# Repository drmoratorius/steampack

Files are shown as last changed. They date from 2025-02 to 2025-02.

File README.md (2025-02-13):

# Dr. Moratorius' SteamPack

**Last Update: 2025-02-13**

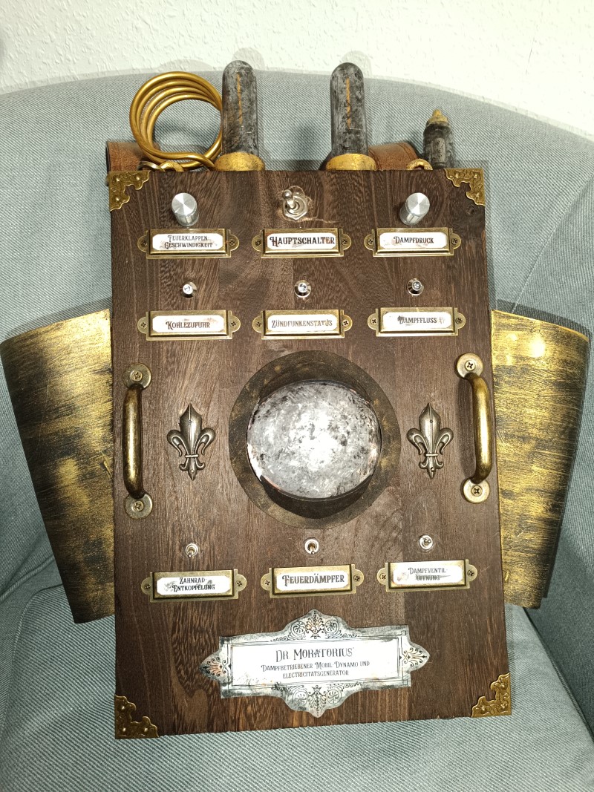
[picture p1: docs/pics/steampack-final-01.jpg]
SteamPack


This is a repository explaining how I built my steam pack and also provide 
all of the required files and information.
Please note that this is more a repository that can help you build your own
or adapt it and not a full tutorial.

## Features
* Powered by USB (power bank)
* Powered by Raspberry Pi Pico 2 W using MicroPython
* Wooden Backpack
* Sounds
* Timed steam (ultrasonic fogger) output with corresponding supporting steam sound
* Sounds when turning on and off certain parts (choose from 255 MP3 files on SD card!)
* and more!

## Electronics Setup
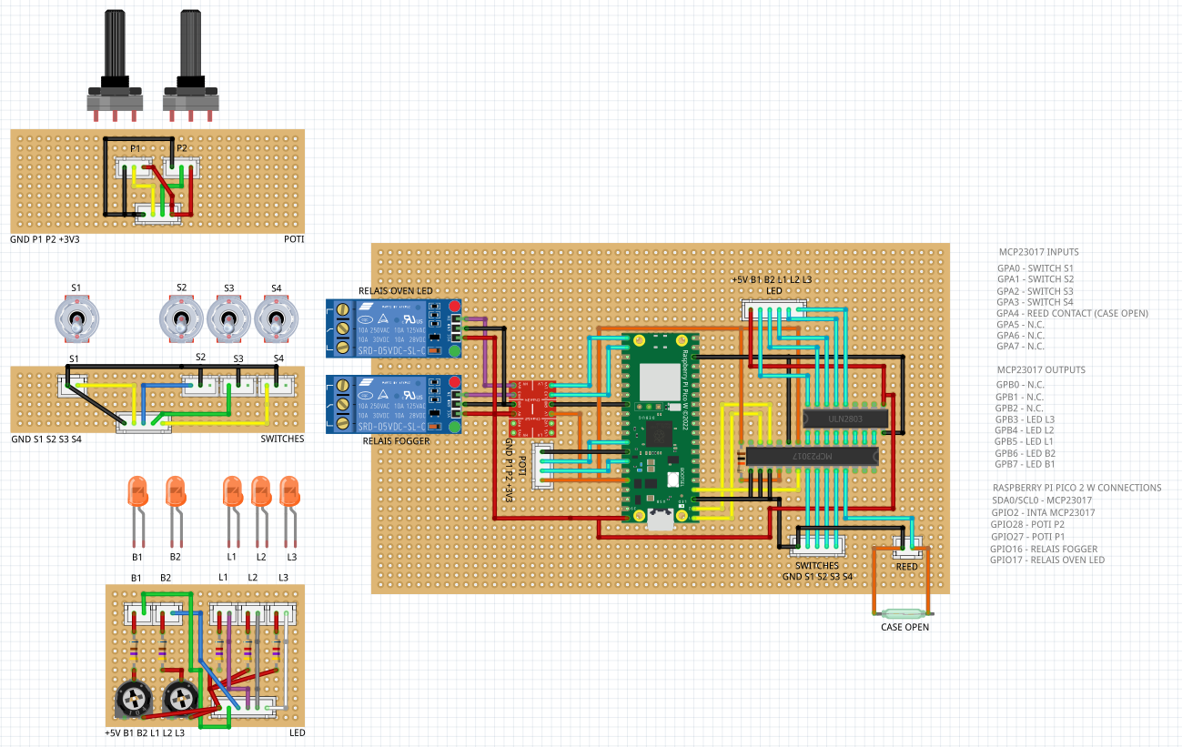
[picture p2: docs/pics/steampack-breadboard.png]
Breadboard

_Please note that this [Fritzing](https://fritzing.org/) layout does not yet contain the sound board!_
* [Raspberry Pi 2 Pico 2 W](https://www.raspberrypi.com/products/raspberry-pi-pico-2/)
* [MCP23017](https://www.microchip.com/en-us/product/mcp23017) (I²C) for handling switch inputs and LED, fogger and "fire" LED utilizing [ULN2803A](https://www.st.com/resource/en/datasheet/uln2804a.pdf) for switching the higher currents
* [MCP23017](https://www.microchip.com/en-us/product/mcp23017) (I²C) and sound board [DY-SV5W](https://grobotronics.com/images/companies/1/datasheets/DY-SV5W%20Voice%20Playback%20ModuleDatasheet.pdf) to play up to 255 different MP3 files from SD card
* separate potentiometer and switch and LED boards for easier placement inside box
* LED board includes potentiometers for setting the intensity
* fogger and LED "fire" switched via relay to enable usage of multiple powerbanks to keep main circuit powered even after draining the fogger or "fire" LED battery
* utilizes level shifters for handling 5V connected to 3V3 ports (relays, sound board)

## Components
* [parts list](docs/PARTS.MD)
* [labels (DOCX)](docs/Schilder.docx)
* [vial holder outer part pattern](docs/Schnittmuster.pdf) - print 100% (do not resize to printer edges) - does not fully cover outer part, but sufficient
* 3D printer files
  * [Vial holder (left) - STL](3d/Moratorius_Steampack_Vial_Holder_R.stl) 
  * [Vial holder (right) - STL](3d/Moratorius_Steampack_Vial_Holder_R.stl)
  * [Vial holder (left) - GCODE for Anycubic i3 MEGA](3d/AIM/AIM_Moratorius_Steampack_Vial_Holder_L.gcode)
  * [Vial holder (right) - GCODE for Anycubic i3 MEGA](3d/AIM/AIM_Moratorius_Steampack_Vial_Holder_R.gcode)
* [Fritzing breadboard layout](fritzing/DrMoratorius-SteamPack-Breadboard.fzz) - still missing schematic and audio part 

## Software
* The code uses the latest MicroPython download from https://www.raspberrypi.com/documentation/microcontrollers/micropython.html
* The source code is available in the `src` directory and still WIP!
* It loads most of the configuration from the `config.json` file, but some parts are (still) hardcoded
* Potential ideas for the future: allow control via smartphone through a WiFi AP

## Sounds
The used sound module [DY-SV5W](https://grobotronics.com/images/companies/1/datasheets/DY-SV5W%20Voice%20Playback%20ModuleDatasheet.pdf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) is using an
SD card (32 GB max, FAT32) with several sounds mixed from available sounds online. Here is a selection:
* https://freesound.org/people/qubodup/sounds/194882/
* https://freesound.org/people/qubodup/sounds/395041/
* https://freesound.org/people/mike_stranks/sounds/407394/
* https://freesound.org/people/craigsmith/sounds/438641/
* https://freesound.org/people/theshaggyfreak/sounds/440453/
* https://freesound.org/people/stib/sounds/487748/
* https://freesound.org/people/Engineer_815/sounds/493558/ (main steam sound used)
* https://freesound.org/people/rottako/sounds/693587/
* https://freesound.org/people/qubodup/sounds/752067/
* https://www.youtube.com/watch?v=LwiOCsfa_ZA (gear sounds)
* https://freesound.org/people/Vibratair/sounds/403892/ (electricity)
* https://freesound.org/people/Halleck/sounds/19487/ (electricity)
* https://freesound.org/people/Vibratair/sounds/403892/ (electricity)
* https://freesound.org/people/opyate/sounds/518945/ (on/off sound - off = reverted)

## How To Build
Please see the [HOWTO](HOWTO.MD)

## Partical Notes
If you use a power bank please keep in mind that most turn off completely if the attached device
does not use a lot of power requiring you to open the case and turn on the powerbank again.
For the future using 18650 cells (with additional protection circuit) with corresponding
charging board might be an option.

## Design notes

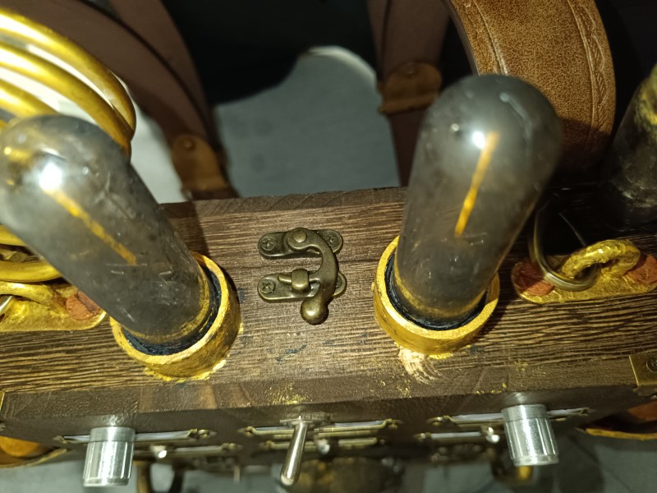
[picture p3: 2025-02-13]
docs/pics/steampack-final-05.jpg

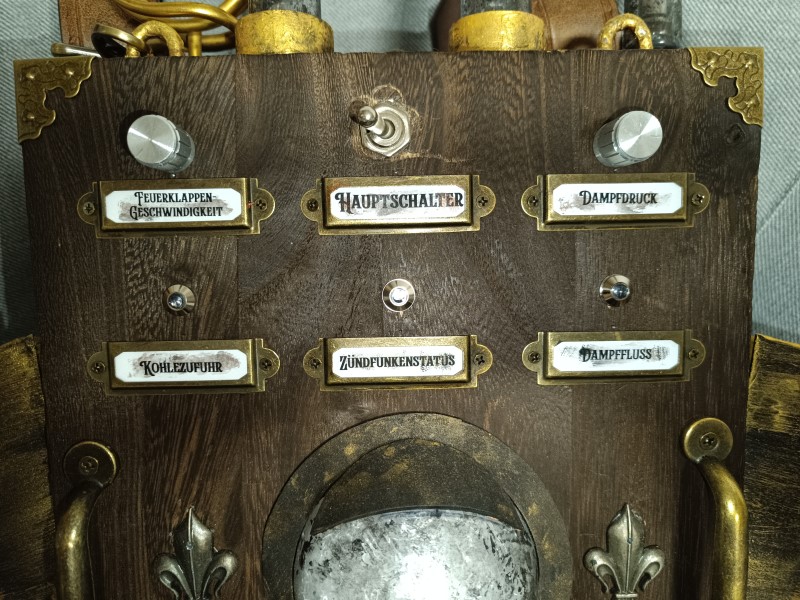
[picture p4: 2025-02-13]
docs/pics/steampack-final-02.jpg

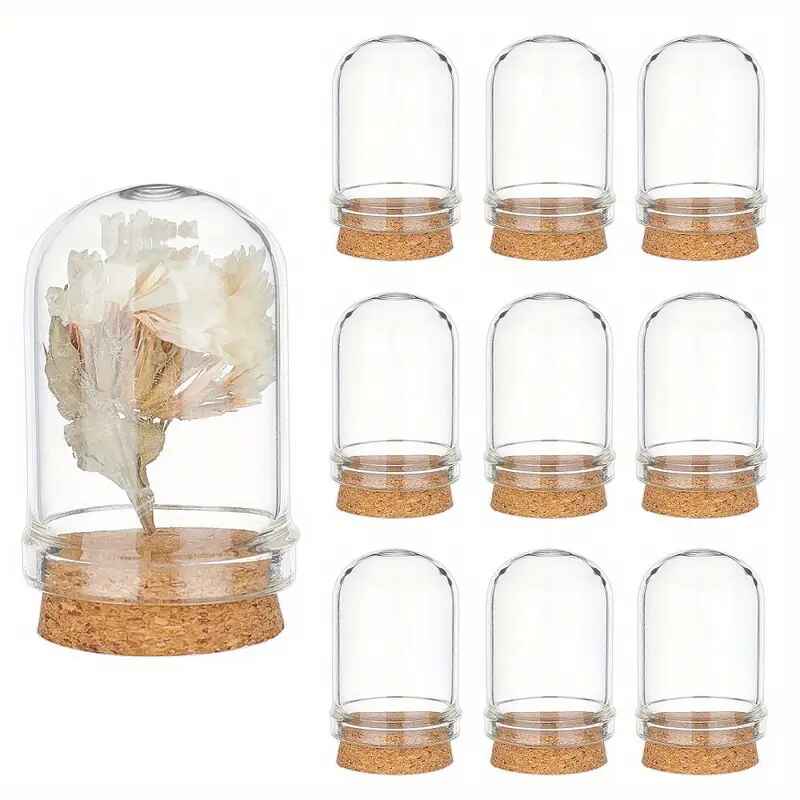
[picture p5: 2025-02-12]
docs/products/mini-glasses.jpg

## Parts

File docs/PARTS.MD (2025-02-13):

# Dr. Moratorius' SteamPack Parts List

Most of the parts have been purchased at AliExpress and Temu. Specifically for Temu
certain products might not be available after some time so please use the corresponding
images to search for the products.

### Mechanical Parts
1. [1 x Wooden Box](https://www.temu.com/search_result.html?search_key=LC451887)
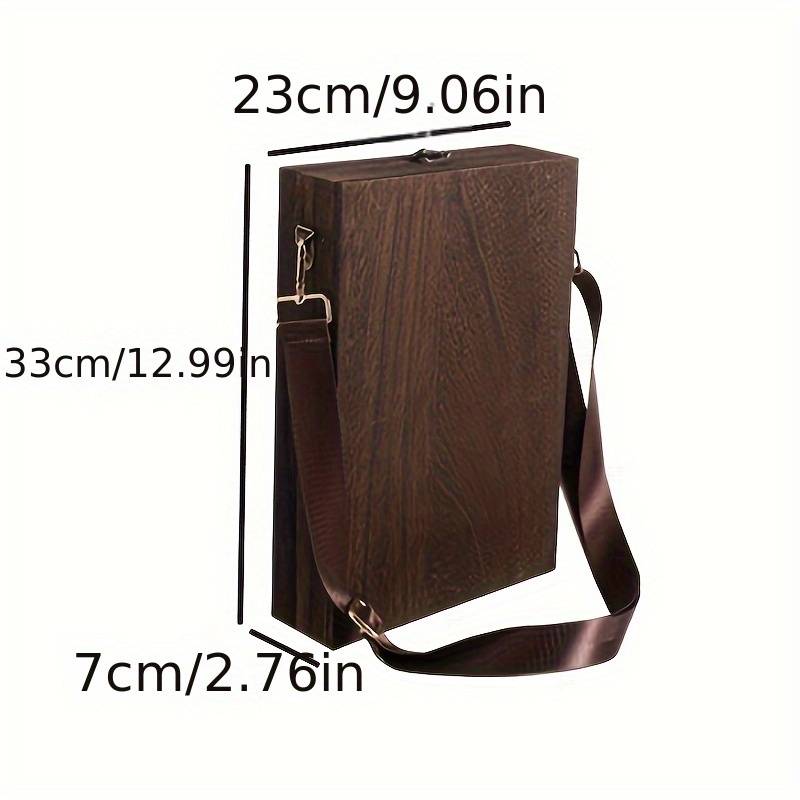
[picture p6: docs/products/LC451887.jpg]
LC451887


2. [2 x Plastic Vials](https://www.temu.com/search_result.html?search_key=TC142422)
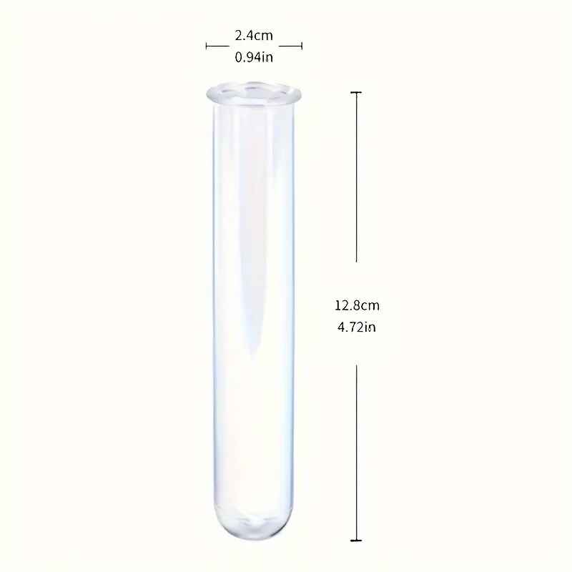
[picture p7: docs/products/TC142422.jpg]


3. [1 x LED USB Flame Light](https://de.aliexpress.com/item/1005005726585637.html)
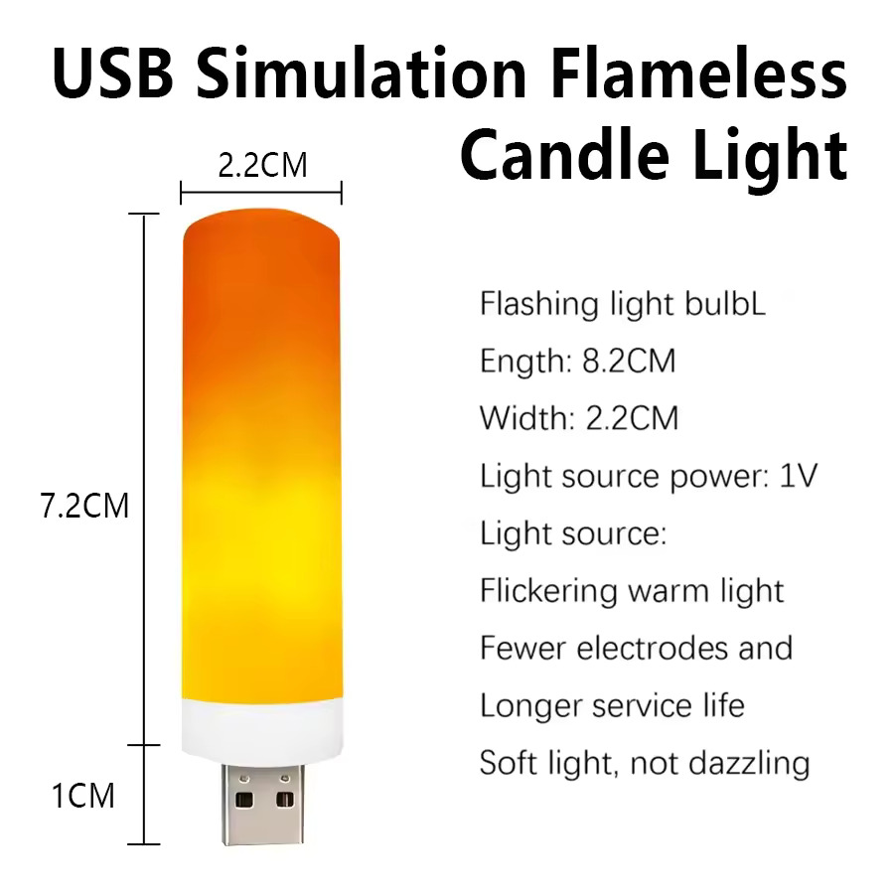
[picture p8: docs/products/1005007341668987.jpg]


3. [4 x Box Metal Edges](https://www.temu.com/search_result.html?search_key=FL13895)
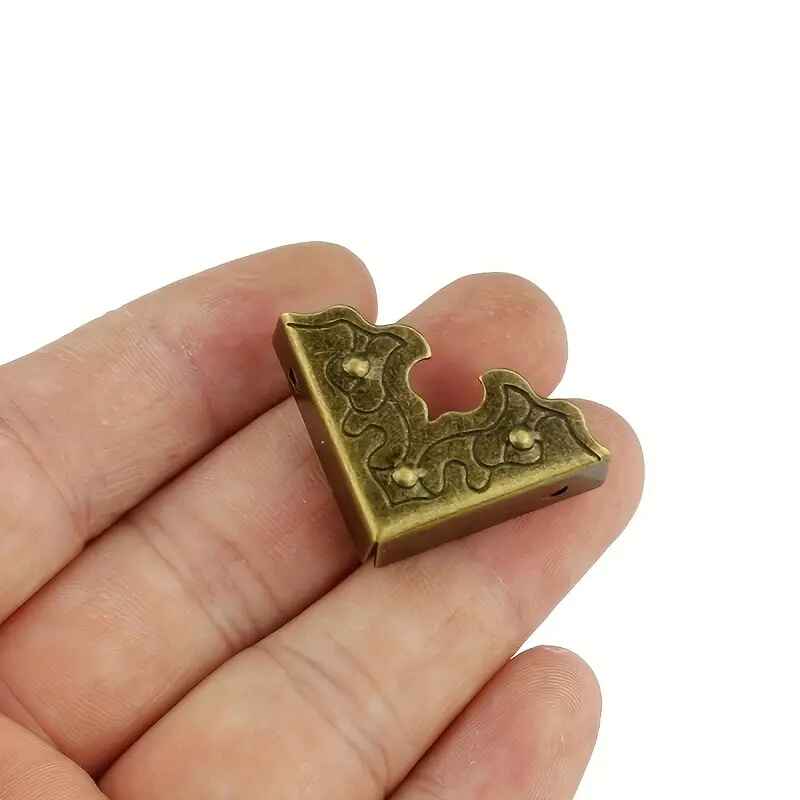
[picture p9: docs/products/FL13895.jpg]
FL13895


4. [2 x Metal Handles](https://de.aliexpress.com/item/1005004053493877.html)
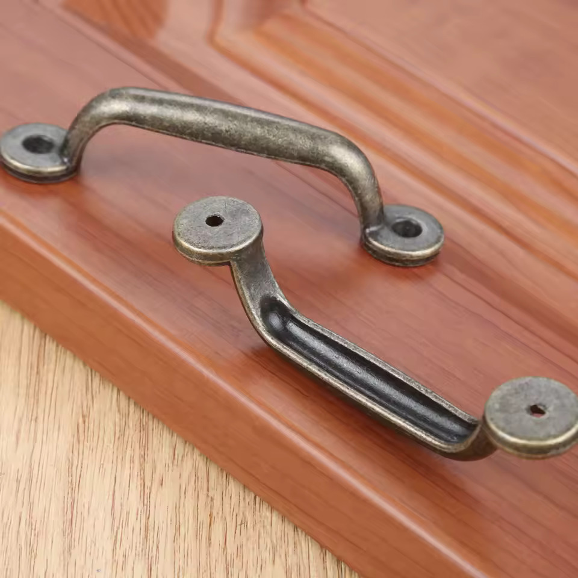
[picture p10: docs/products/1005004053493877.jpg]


5. [12 x Label Holder](https://www.temu.com/search_result.html?search_key=MQ356547)
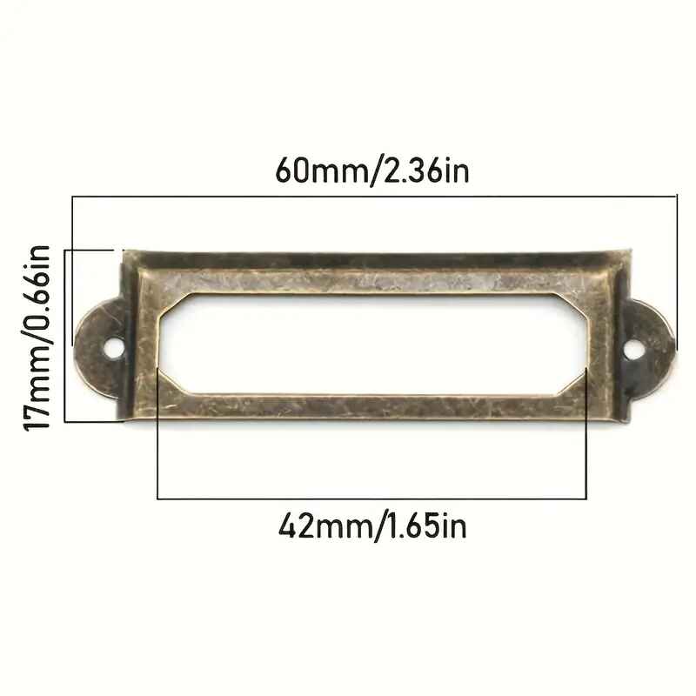
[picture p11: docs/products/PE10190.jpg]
PE10190


6. [2 x Fleur de Lis](https://www.temu.com/search_result.html?search_key=MQ356547)
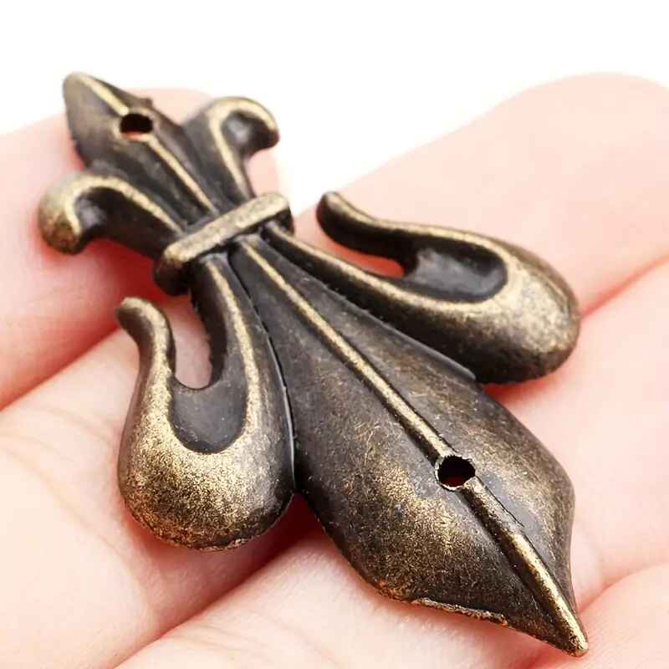
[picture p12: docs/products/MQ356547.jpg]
MQ356547


7. [2 x Bottom Holder for Belt Holder](https://de.aliexpress.com/item/1005004164705575.html)
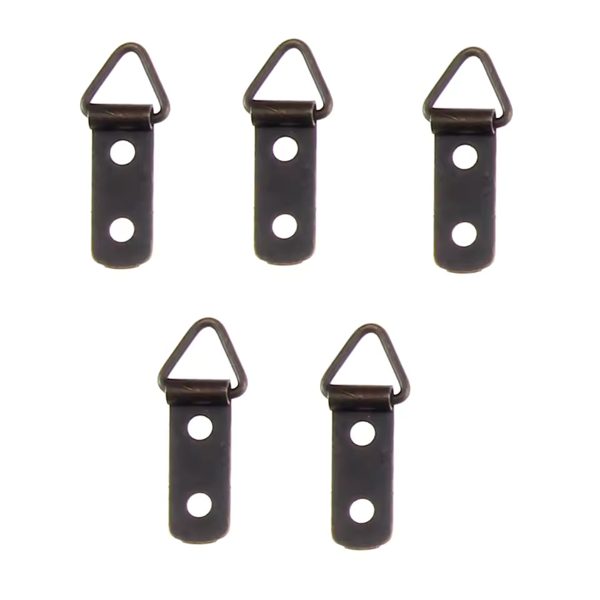
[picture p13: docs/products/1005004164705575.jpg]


8. [4 x Belt Holder (3,8 cm)](https://de.aliexpress.com/item/1005005033070778.html)


9. [2 x Top Holder for Belt Holder](https://de.aliexpress.com/item/1005006681139131.html)


10. [2 x Belt (3,8 cm)](https://de.aliexpress.com/item/1005008235359138.html)


11. [2 x Edison Lamp 3V](https://de.aliexpress.com/item/1005006271054067.html)


12. [1 x Plastic Dome](https://de.aliexpress.com/item/1005006147670192.html)


13. [4 x Bottom Feet](https://de.aliexpress.com/item/1005006509639025.html)


14. [3 x LED 5mm orange clear](https://de.aliexpress.com/item/1005003323749658.html)


15. [1 x Audio Module DY-SV5W](https://de.aliexpress.com/item/1005005892075405.html)


16. [1 x Switch large](https://de.aliexpress.com/item/1005006091626384.html)


17. [2 x Ultrasonic fogger without button](https://de.aliexpress.com/item/1005007294513729.html)


18. [2 x Fogger holder (long)](https://de.aliexpress.com/item/1005005056005707.html)


16. [2 x Fogger extension cable](https://de.aliexpress.com/item/1005006091626384.html)


17. [2 x USB-C Connector](https://de.aliexpress.com/item/1005005187689195.html)


18. [Speaker - 5W 4 Ohms](https://www.amazon.de/dp/B0CSSSWSBQ)

## Additionally (not specifically ordered when building):
* 3 x metal switch small
* 2 x potentiometer (10K/100K) + knob

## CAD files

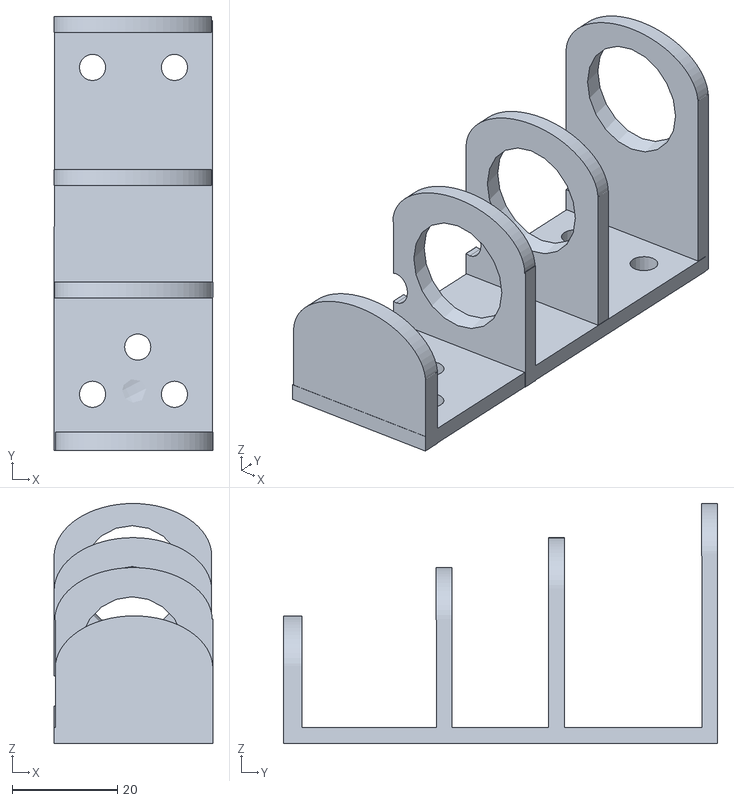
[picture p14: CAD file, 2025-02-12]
3d/Moratorius_Steampack_Vial_Holder_R.stl
30.2 x 82.6 x 45.7

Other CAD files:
3d/Moratorius_Steampack_Vial_Holder_L.stl

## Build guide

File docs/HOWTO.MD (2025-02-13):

# How To Build Dr. Moratorius' SteamPack

**Please note: This is more of a reference than a full tutorial!**

## 1. Box & Transport
The base is a wooden box (see [parts](PARTS.MD)) which can be opened easily and has a simple lock. Instead of the original
way to transport the box two new mounting options are used so that the box can be transported as a backpack using belts.

Belt:
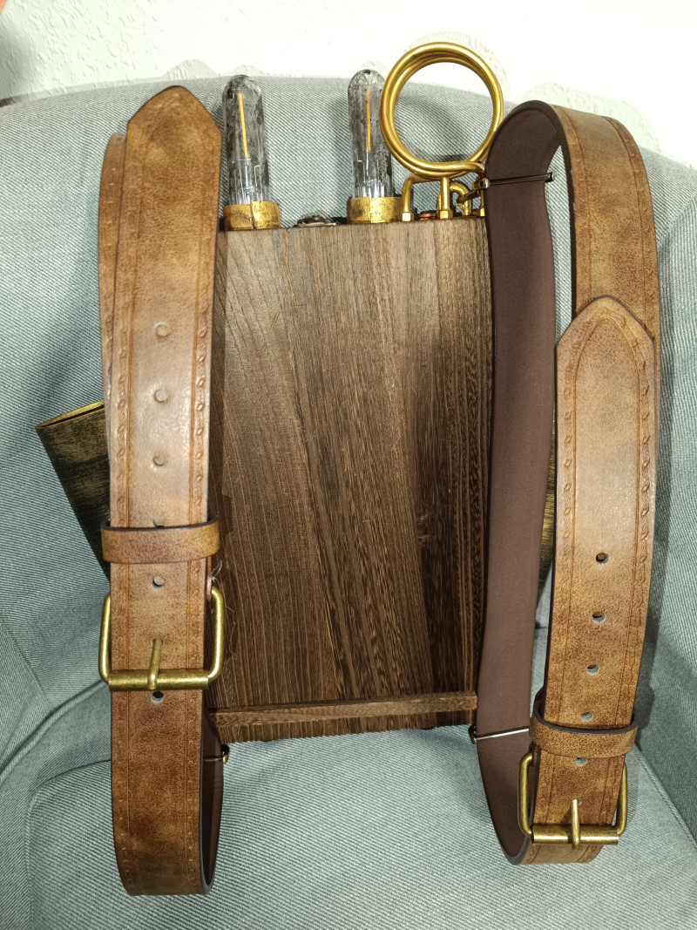
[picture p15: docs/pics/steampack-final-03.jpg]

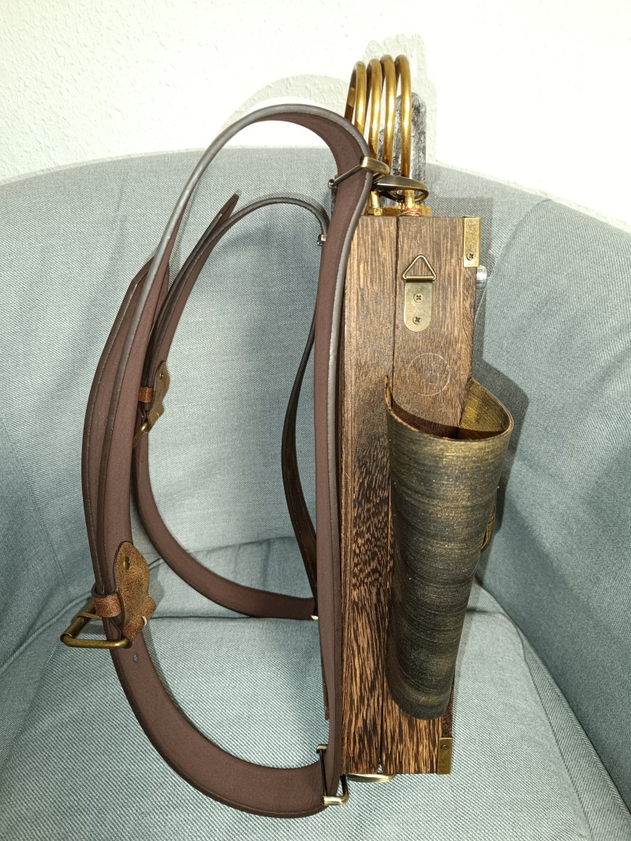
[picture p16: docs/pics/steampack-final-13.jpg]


Belt mounting:
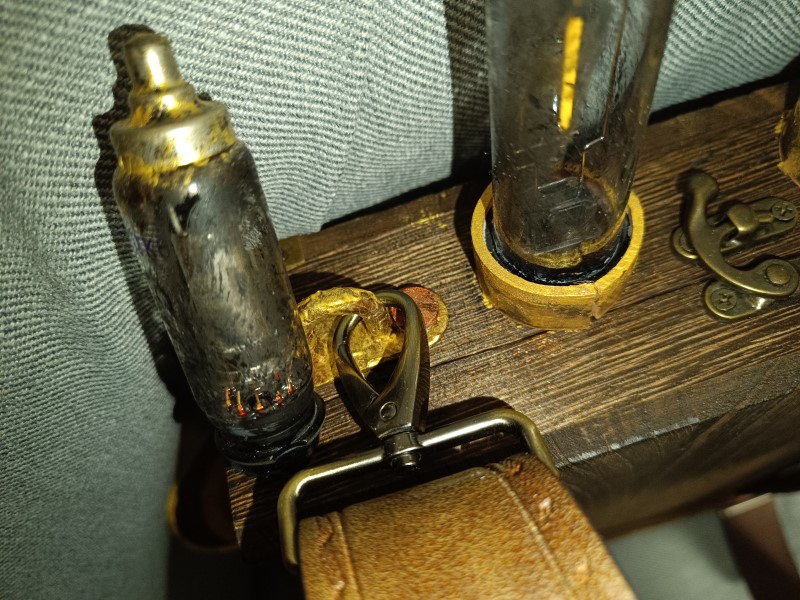
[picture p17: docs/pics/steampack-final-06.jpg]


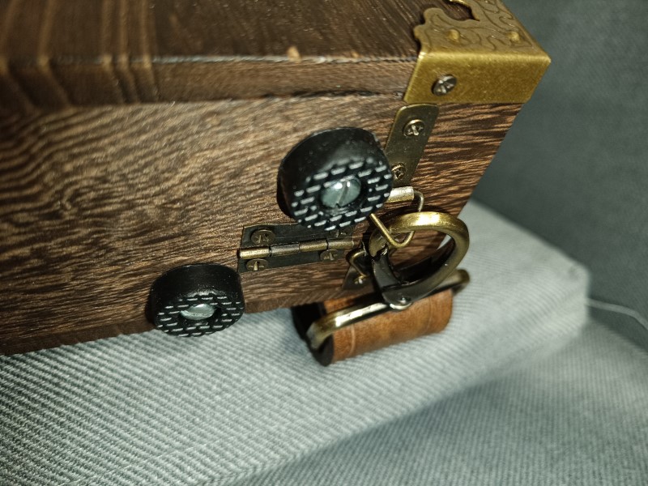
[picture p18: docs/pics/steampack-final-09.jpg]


In addition to allow to place it standing up on a table additional parts have been added:

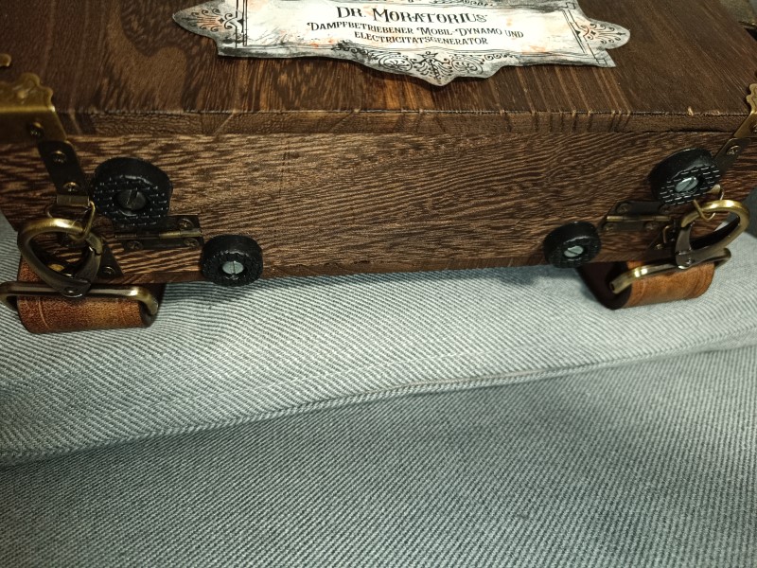
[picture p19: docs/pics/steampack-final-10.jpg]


 ## 2. LEDs, Switches and Labels

For the LEDs and switches holes have been drilled. The labels have been screwed in directly with the provided screws.
Two large Edison-style LEDs with 3V are used and three clear orange LEDs to simulate old-style glow lamps.
Furthermore, an old cathode ray tube has been used with a simple warm white LED glued to the bottom.

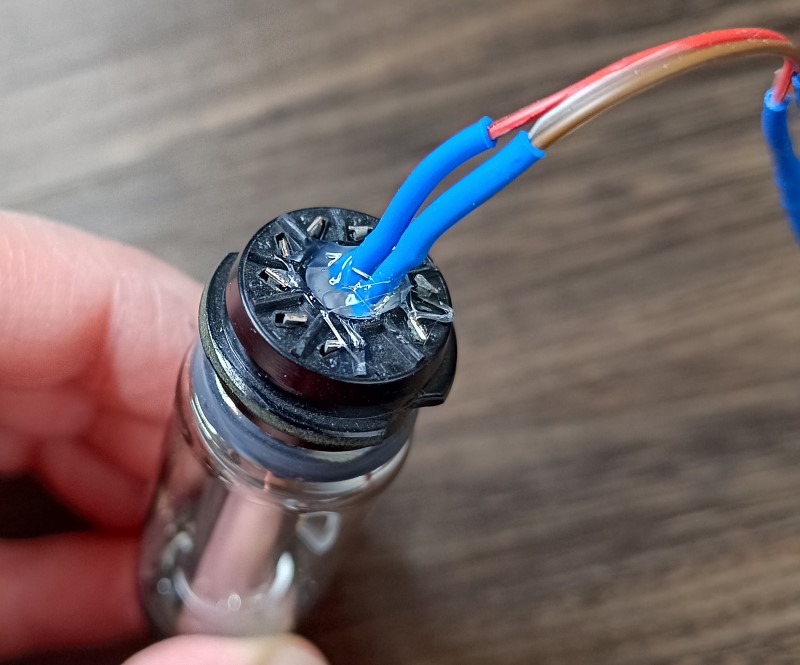
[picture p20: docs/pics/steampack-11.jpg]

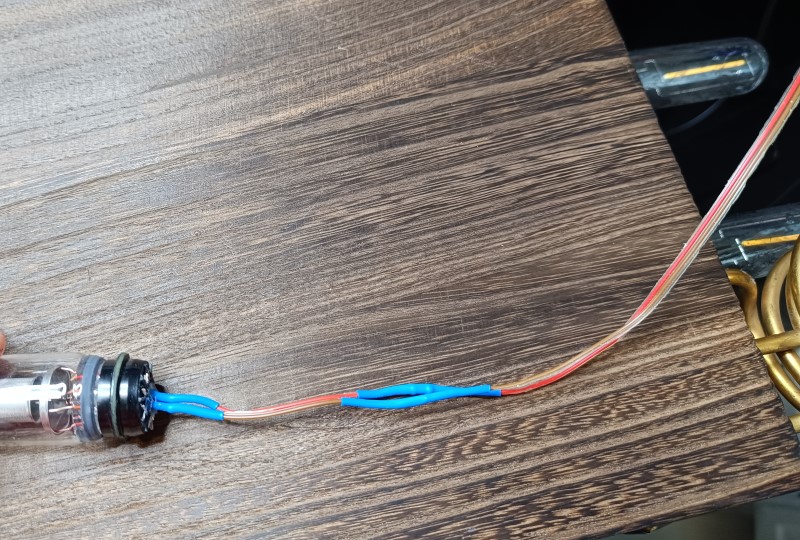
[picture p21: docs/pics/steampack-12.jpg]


All of the elements have been "aged" using acrylic colors.

## 3. Simulated Fire

The simulated fire of the presumed steam engine is created using a simple USB LED flicker light where the top and bottom
parts have been removed and cables soldered directly to the +5V and GND pins.
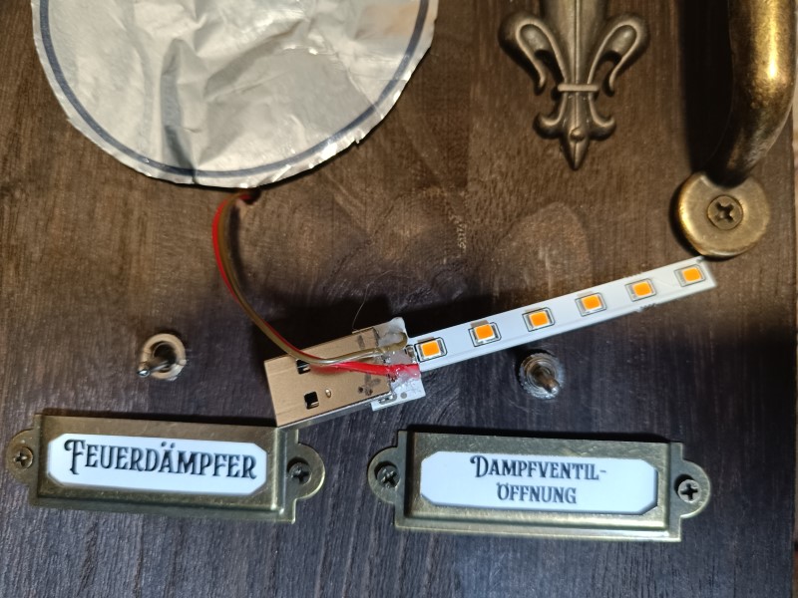
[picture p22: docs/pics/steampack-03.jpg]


A plastic dome is used and is filled with simple clear plastic foil at the bottom and top surrounding the LED flicker light.

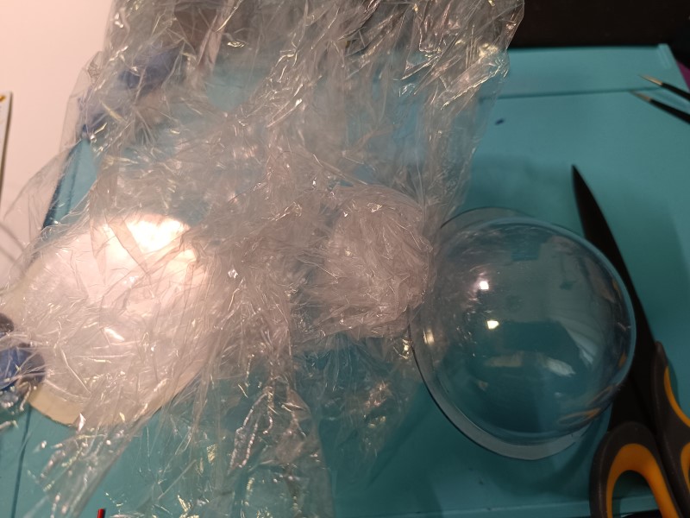
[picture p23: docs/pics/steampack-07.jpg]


For best lighting the bottom is made from cardboard and covered with aluminium foil which then again is covered by clear
packing tape to prevent any shorts through the aluminium.

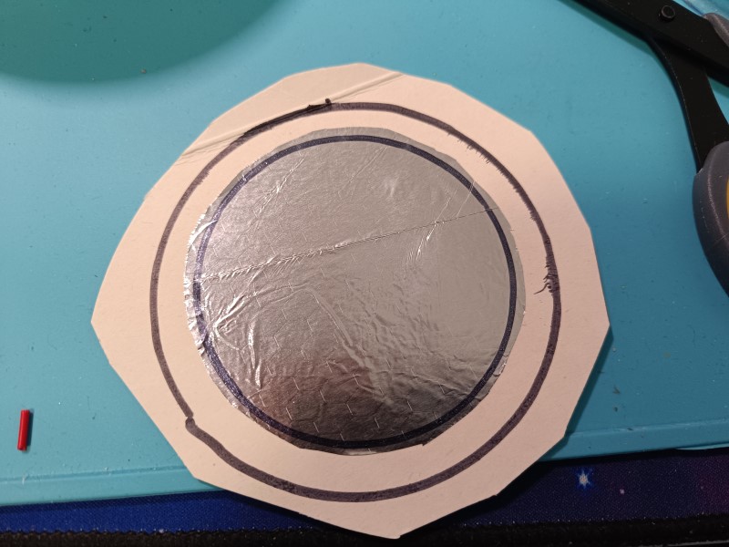
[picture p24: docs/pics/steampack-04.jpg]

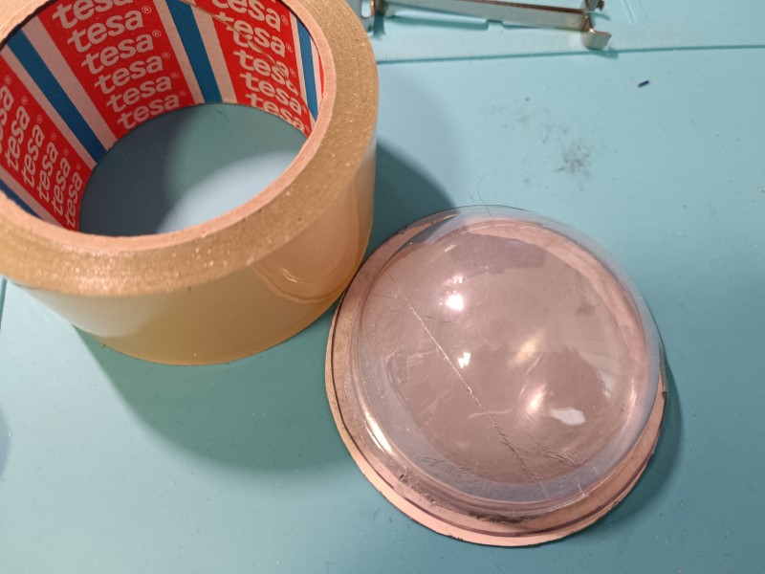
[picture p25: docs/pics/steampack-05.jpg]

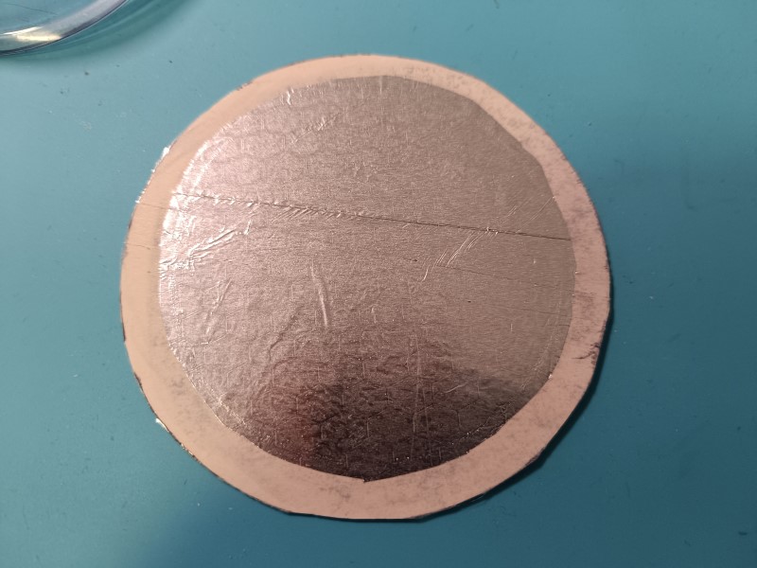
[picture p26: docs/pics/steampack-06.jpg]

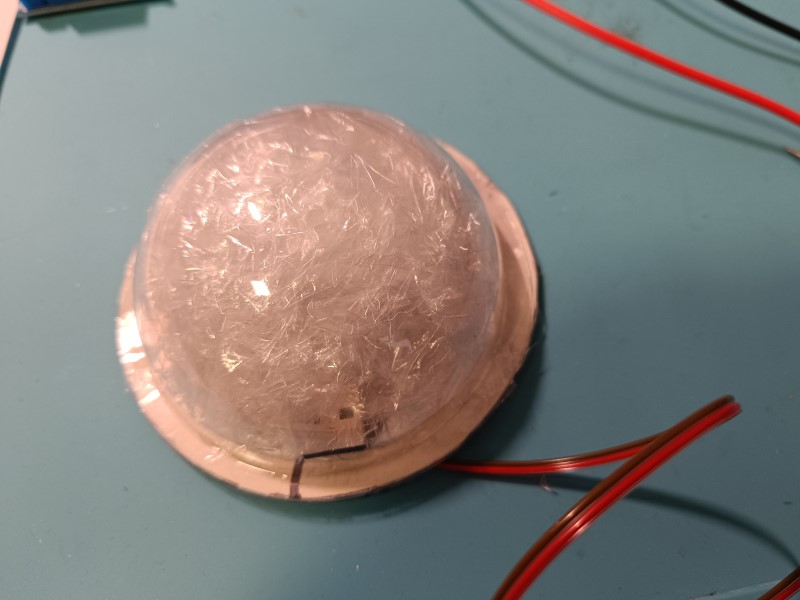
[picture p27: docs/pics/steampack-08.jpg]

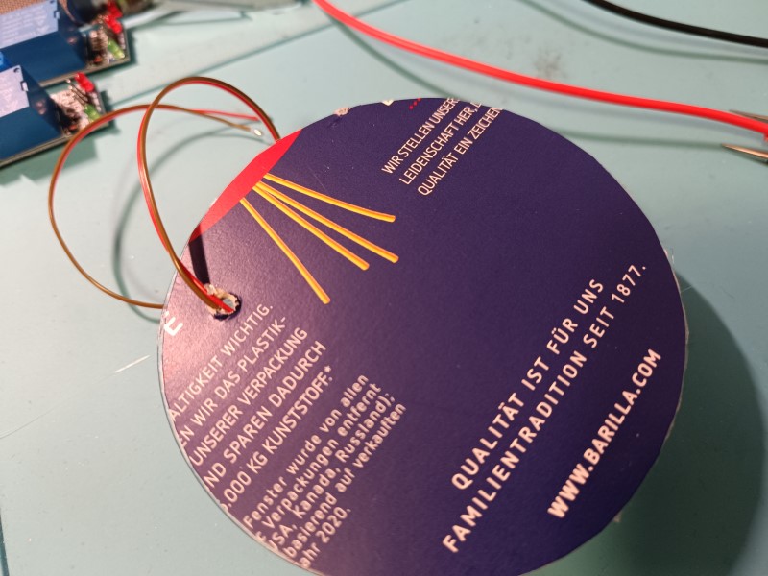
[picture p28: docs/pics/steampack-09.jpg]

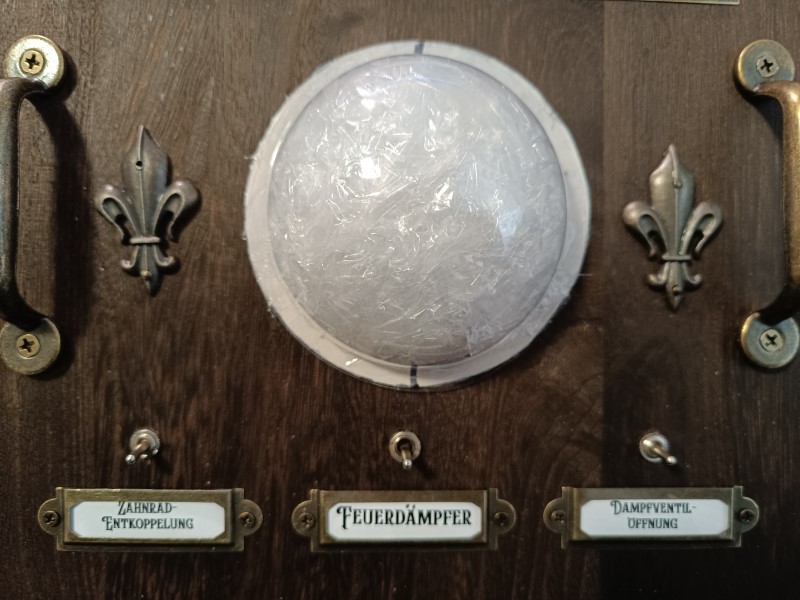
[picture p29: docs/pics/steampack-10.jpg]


Is is then covered with some foam rubber parts that have been painted with acrylic colors.

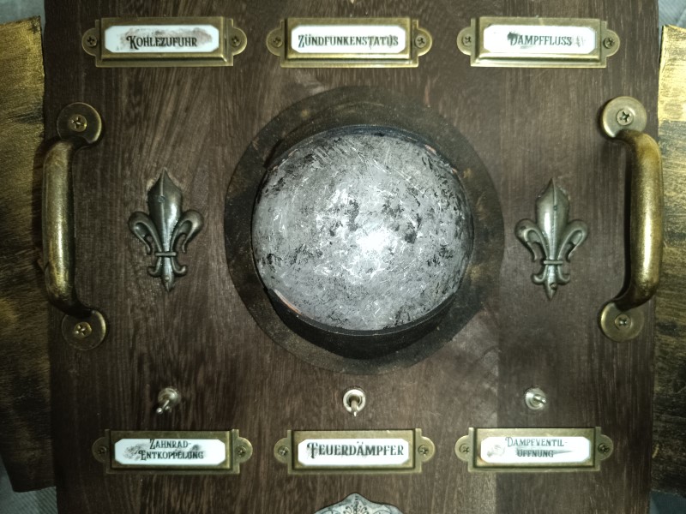
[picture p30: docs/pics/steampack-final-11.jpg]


## 4. Foggers ("Steam")

The foggers are ultrasonic mist boards connected to a piezo speaker that you can buy as a complete part.
However, when purchasing the boards without buttons (which are working as long as they have USB power) the extensions
are a bit short so different ones were used (see [parts list](PARTS.MD) for details).

These things are then put into plastic vials which are held by 3d-printed vial holders made specifically for this
project. You can download the files from the `3d` directory.

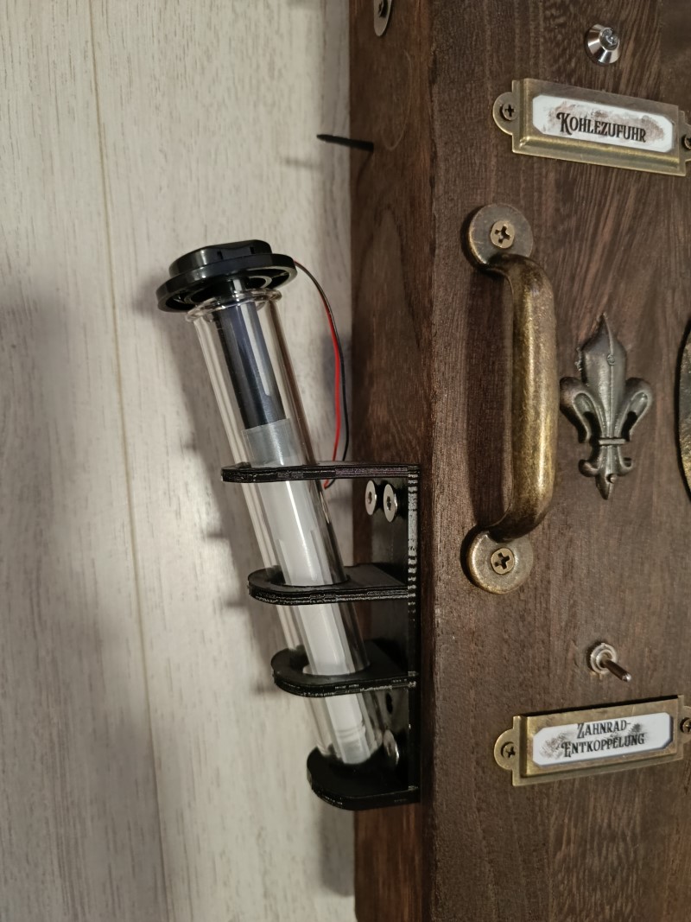
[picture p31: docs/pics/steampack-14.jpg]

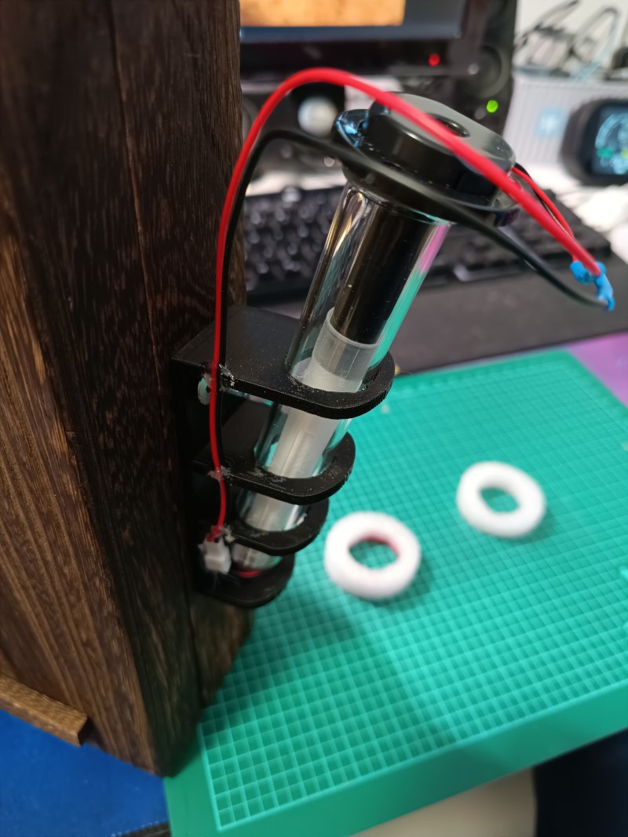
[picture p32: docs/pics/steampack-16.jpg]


However, when using these you have to take into account that you will have to pour in new water if all of it has
been used up. To achieve this the original cables are made longer using extension cables. Also, the boards are inside
the wooden box. That means even if overfilled it will simply drip to the floor and not reach any electronics. 

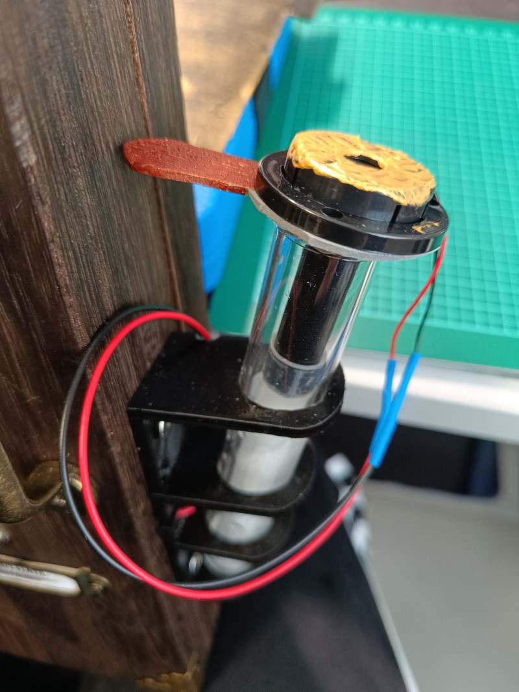
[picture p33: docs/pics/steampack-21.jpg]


They are also covered with simple foam rubber parts so that you can easily take them out if the vials need to be 
refilled.

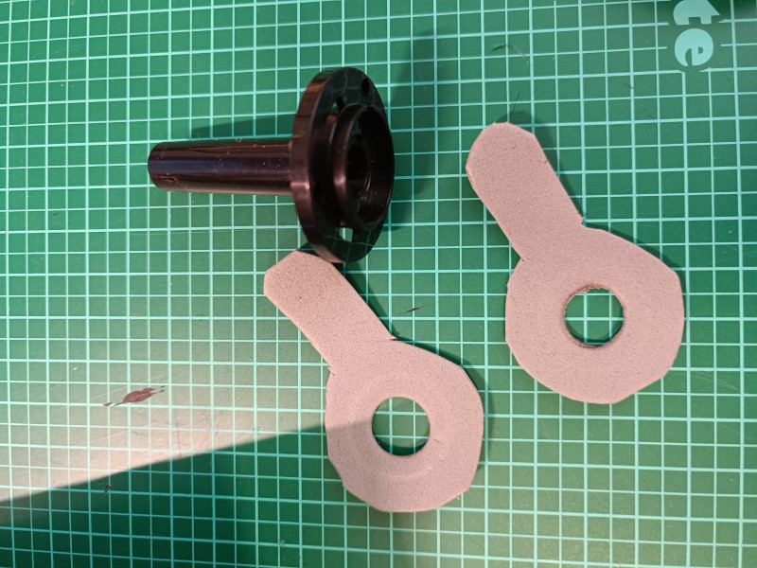
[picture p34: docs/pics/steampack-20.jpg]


The foggers are also covered with some simple foam part:

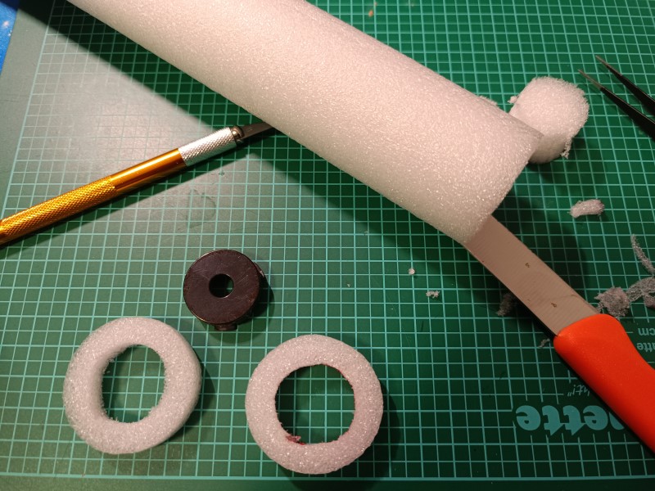
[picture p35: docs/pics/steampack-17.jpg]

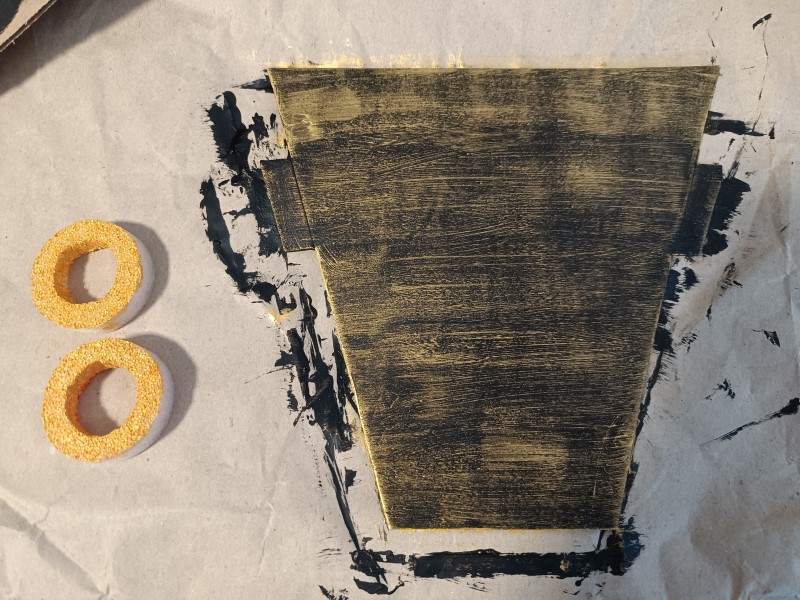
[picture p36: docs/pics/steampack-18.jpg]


The vial holders are then covered with more foam rubber painted black and gold to achieve a brass-like coloring.

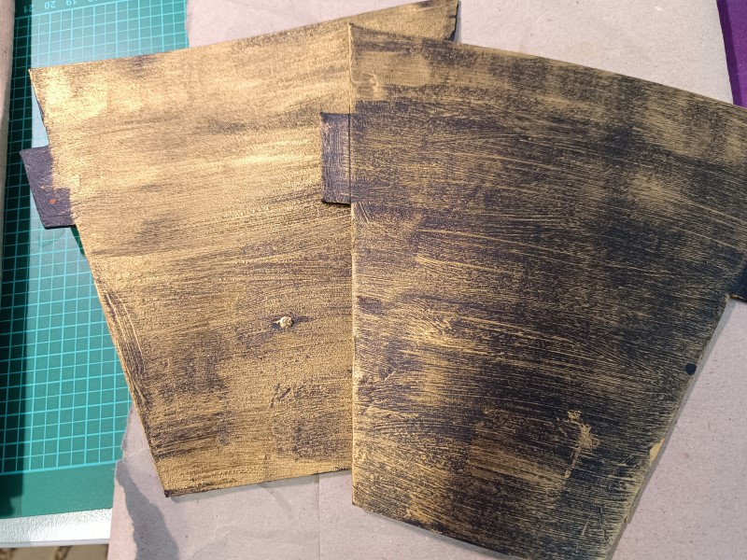
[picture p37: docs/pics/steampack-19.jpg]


There is a pattern available for them you can print (do not resize when printing, otherwise it won't fit).
Actually the coverings are a bit too large which means that the "outer" part of the vials cannot stick to the holder,
but is still holds perfectly when using superglue on all sides of the vial holder.

Please note that you have to be able to take out the full foggers so the cable needs to be long enough.

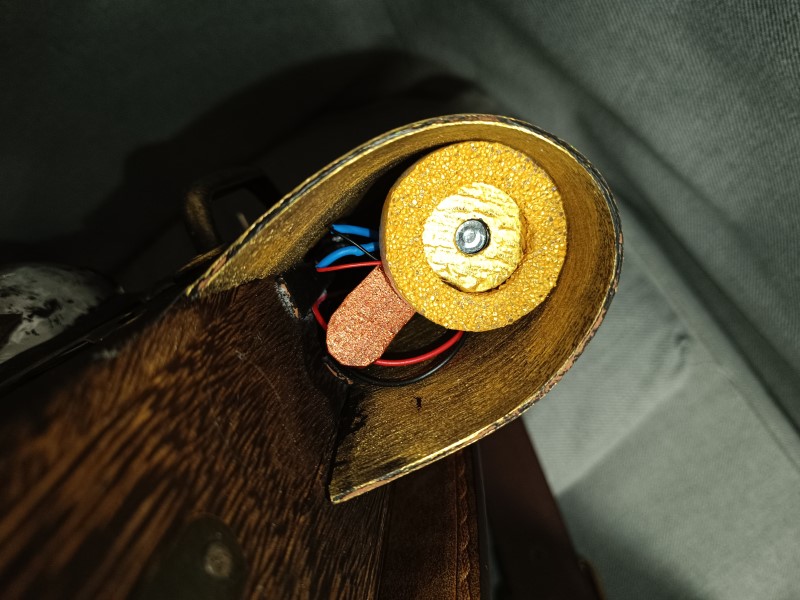
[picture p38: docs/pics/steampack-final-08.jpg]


## 5. Sound

For sound the sound module DY-SV5W is used. It features several modes and the one used uses its 8 inputs to specify
the MP3 file to be played (`00001.mp3` - `00255.mp3`). The MP3 files are stored with respective names in the root of
the microSD card (max. 32 GB card supported - with FAT32 formatted).

The sound list can be found on the [home](README.MD) page.

## 6. Sound Functionality

The software plays certain sounds when certain switches are switched and always when steam is emitted to greatly
enhance the effect, because the foggers don't really create any audible sound at all so people are a bit confused
(hopefully) on the sound.

A simple 5W 4 ohms speaker is used attached to the sound board and its volume set accordingly through the built-in
potentiometer.

## 7. The Rest

The curly metal part I got from ebay from an old machine so I don't know any source to buy it.
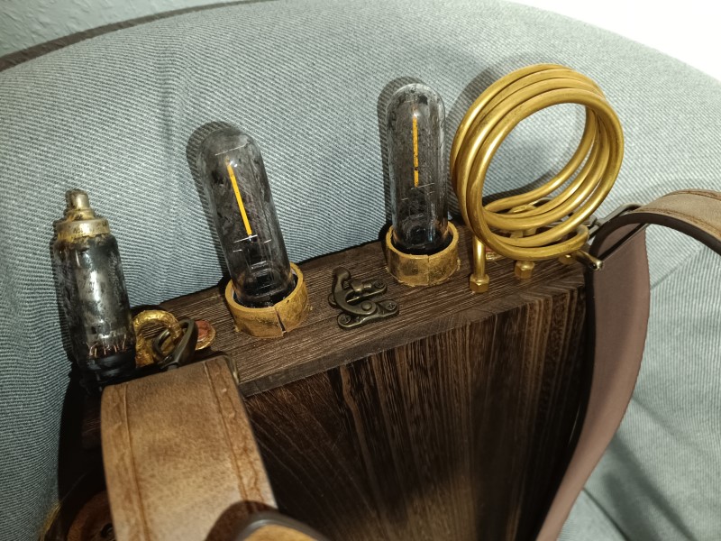
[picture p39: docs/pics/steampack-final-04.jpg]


It also features a "case open" reed contact to stop any program when opening the box (you usually don't want to get the
fog in your face there).

## 8. Electronics In The Box
As this essentially is a prototype it doesn't really look great from the inside. Creating a PCB for everything would
be a perfect addition (I know).

Everything's simply screwed or glued in there to ensure that it stays in place. 

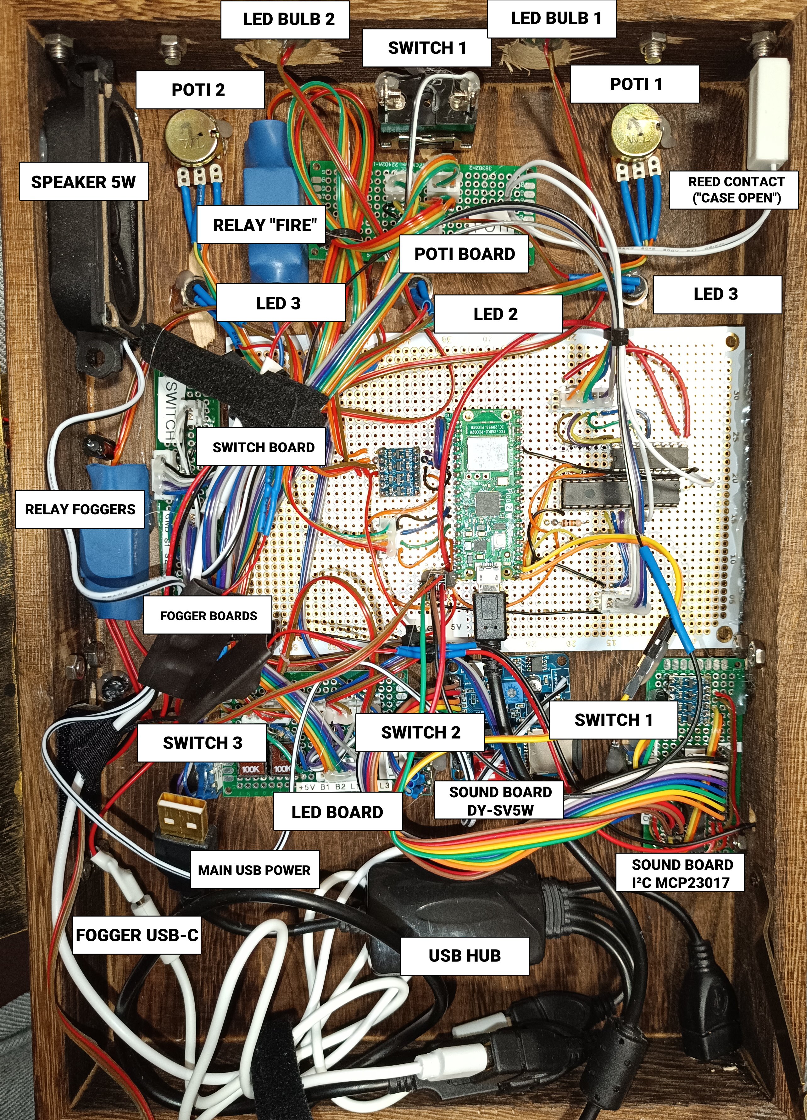
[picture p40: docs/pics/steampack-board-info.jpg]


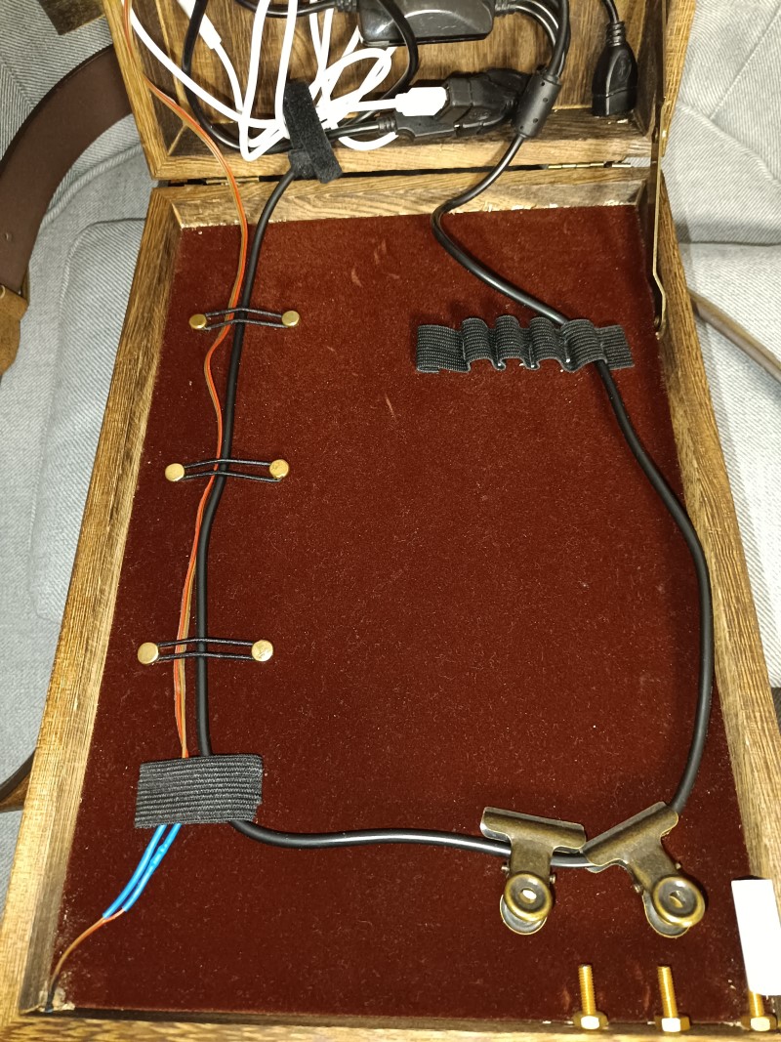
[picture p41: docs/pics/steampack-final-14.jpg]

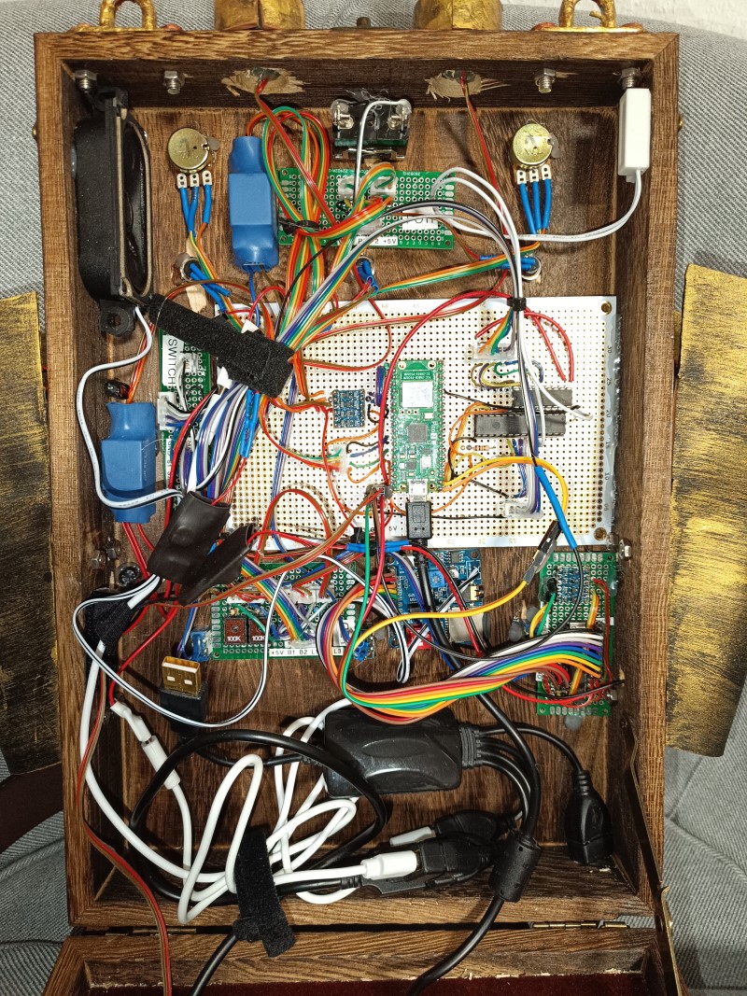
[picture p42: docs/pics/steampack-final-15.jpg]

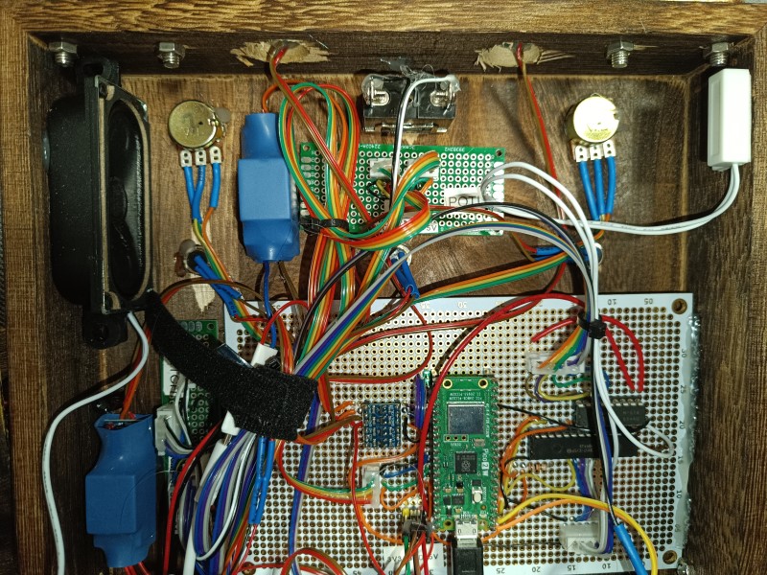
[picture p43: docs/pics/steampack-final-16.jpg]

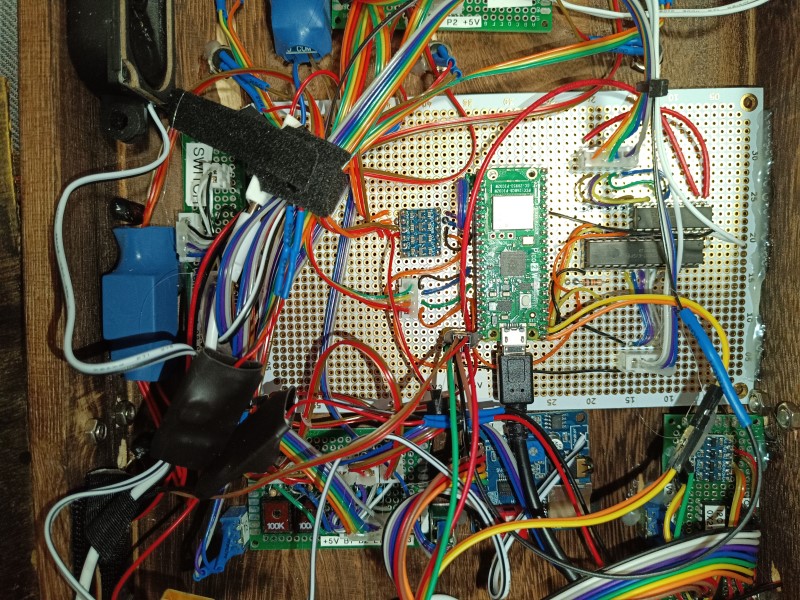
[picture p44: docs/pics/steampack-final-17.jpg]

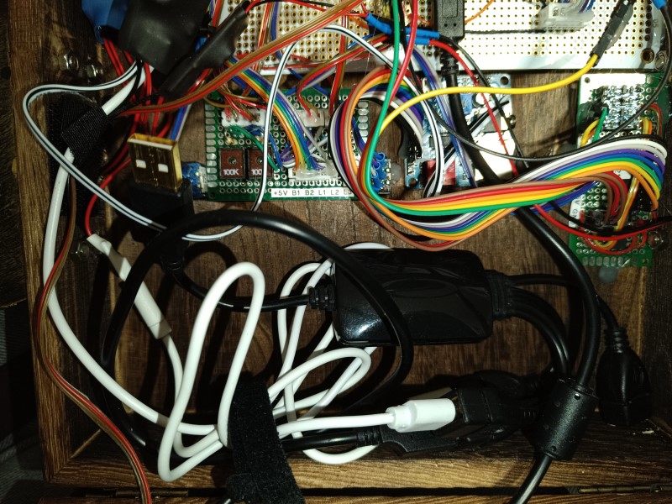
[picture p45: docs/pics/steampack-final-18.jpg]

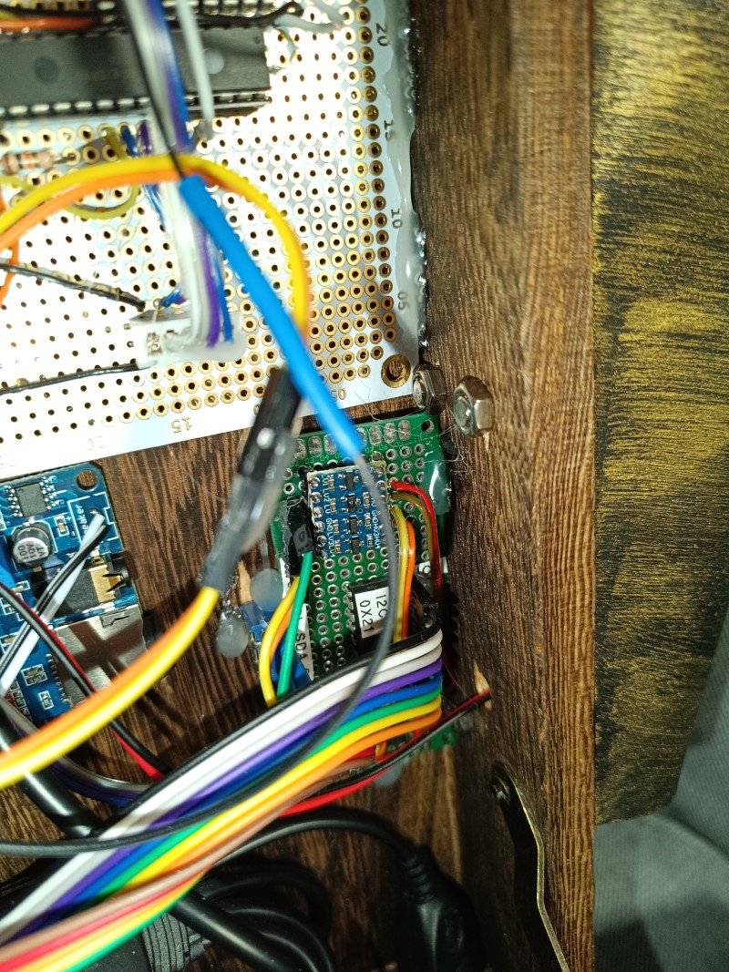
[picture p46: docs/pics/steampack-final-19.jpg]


I hope you like it! :)

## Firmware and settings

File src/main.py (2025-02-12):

from morutils import *
from steampack import *
import uasyncio as asyncio
import time

##############
### CONFIG ###
##############
# Config is read from config.json file so that no code needs to be changed for changing the configuration!
config = UTIL_getJSON('config.json')

# Initial values/always holding the current values at any time
currentState = config['defaultValues']
lastState = currentState

## Variables for runtime
steamOn = False
steamCurrentlyOn = False
lastSteamOn = time.time() - (60 * 60 * 24)
startTs = time.time()
mcp2Found = False
soundActive = False

##########################
### CALLBACK FUNCTIONS ###
##########################

def playSound(no):
    if mcp2Found and soundActive:
        SP_playSound(no)
        time.sleep(0.05)
        SP_stopPlayingSound()
    
# MAIN PROGRAM
# Handles the current state, i.e. updates everything
def handle_current_state(currentStateNew):
    global currentState, steamOn, steamCurrentlyOn, lastSteamOn, soundActive
    currentState = currentStateNew
    if currentState['REED'] == False or currentState['S1'] == False:
        print('[X] Case open or main switch turned off')
        # Case open, turn all off OR main switch turned off
        sp_switchRelais(1, False)
        sp_switchRelais(2, False)
        currentState = SP_switchLedS1(currentState, False)
        currentState = SP_switchLedS2(currentState, False)
        currentState = SP_switchLedS3(currentState, False)
        currentState = SP_switchLedB1(currentState, False)
        currentState = SP_switchLedB2(currentState, False)
    else:
        if currentState['S1'] == True and currentState['REED'] == True:
            print('[X] Case closed and main switch turned on')
            
            if currentState['S2'] == True:
                # TODO: Zahnradenkoppelung
                print('[X] S2 Zahnradenkoppelung ON')
                currentState = SP_switchLedS1(currentState, False)
                soundActive = False
            else:
                # TODO: Zahnradenkoppelung
                print('[X] S2 Zahnradenkoppelung OFF')
                currentState = SP_switchLedS1(currentState, True)
                soundActive = True
                
            if currentState['S3'] == True:
                # Feuerdämpfer (ON = fire off)
                print('[x] Turning off fire')
                sp_switchRelais(1, False)
                currentState = SP_switchLedS2(currentState, False)
            else:
                # Feuerdämpfer (OFF = fire on)
                print('[x] Turning on fire')
                sp_switchRelais(1, True)
                currentState = SP_switchLedS2(currentState, True)
                
            # TODO FOGGER: only exactly when fogging turn on B1 and B2? FLicker?
            # TODO Read dampfdruck poti and the more far right the more often it should happen
            if currentState['S4'] == True:
                # Dampfventilöffnung (ON = Fogger ON)
                # TODO
                print('[x] Turning on fogger program')
                currentState = SP_switchLedS3(currentState, True)
                currentState = SP_switchLedB1(currentState, True)
                currentState = SP_switchLedB2(currentState, True)
                time.sleep(1)
                steamOn = True
                steamCurrentlyOn = False
                lastSteamOn = startTs
            else:
                # Dampfventilöffnung (OFF = Fogger OFF)
                # TODO
                print('[x] Turning off fogger program')
                currentState = SP_switchLedS3(currentState, False)
                currentState = SP_switchLedB1(currentState, False)
                currentState = SP_switchLedB2(currentState, False)
                steamOn = False
                
    lastState = currentState
    

# Always receives an array of values: [['SP1', True], ['SP2', False]]...
def input_callback(changes):
    global currentState, lastSteamOn, steamOn, soundActive
    print('---> INPUT CALLBACK')
    print(changes)
    for change in changes:
        currentState[change[0]] = change[1]
        
        if change[0] == 'poti2':
            lastSteamOn = startTs - (60 * 60 * 24) # reset so that it takes immediate effect
            steamInterval, steamDuration = getSteamDurations()
            print('POTI2 changed steamInterval', steamInterval, 'duration', steamDuration)

        if change[0] == 'S1':
            if change[1] == False:
                steamOn = False
                playSound(12)
            else:
                steamOn = currentState['S4']
                playSound(11)
                
        if change[0] == 'S2':
            soundActive = not change[1]
            
        if change[0] == 'S3':
            if change[1] == True:
                playSound(13)
            else:
                playSound(14)
            
        if change[0] == 'S4':
            lastSteamOn = startTs - (60 * 60 * 24)
            if change[1] == True:
                playSound(15)
            else:
                playSound(16)

    print(currentState)
    
    handle_current_state(currentState)
 
# TODO: this should be in config.json instead!
def getSteamDurations():
    curPercentage = currentState['poti2'];
    steamInterval = 300
    steamDuration = 5
    
    if curPercentage < 10:
        steamInterval = 240
        steamDuration = 5
    elif curPercentage < 25:
        steamInterval = 120
        steamDuration = 7
    elif curPercentage < 50:
        steamInterval = 60
        steamDuration = 3
    elif curPercentage < 75:
        steamInterval = 30
        steamDuration = 2
    elif curPercentage <= 100:
        steamInterval = 10
        steamDuration = 3
        
    #print('steamInterval', steamInterval, 'duration', steamDuration)
    return steamInterval, steamDuration

###################
### ASYNC SETUP ###
###################
async def function1():
    while True:
        SP_getCurrentPotiValue(1)
        SP_getCurrentPotiValue(2)
        await asyncio.sleep(0.25)
        
async def function2():
    global steamCurrentlyOn, lastSteamOn
    while True:
        steamInterval, steamDuration = getSteamDurations()
        #print("Function 2 is running")
        curTs = time.time()
        #print('#STEAM async function')
        if steamOn:
            #print('#STEAM switch is currently on')
            if not steamCurrentlyOn:
                #print('#STEAM switch is currently on, but fogger not')
                if curTs - lastSteamOn > steamInterval:
                    #print('#STEAM switch is currently on, but fogger not, longer than 10 seconds ago, turning on')
                    lastSteamOn = curTs
                    sp_switchRelais(2, True)
                    print('!STEAM! ON')
                    steamCurrentlyOn = True
                    playSound(4)
            else:
                if curTs - lastSteamOn > steamDuration:
                    #print('#STEAM switch is currently on, and fogger also, but longer than 2 seconds, turning off')
                    lastSteamOn = curTs
                    sp_switchRelais(2, False)
                    print('!STEAM! OFF')
                    steamCurrentlyOn = False
        else:
            # Not on, so ensure it's off - this is required for when the user switches during run
            #print('#STEAM switch is currently OFF, turning off fogger')
            steamCurrentlyOn = False
            lastSteamOn = startTs
            sp_switchRelais(2, False)
            
        await asyncio.sleep(1)

# Run both functions concurrently
async def main():
    task1 = asyncio.create_task(function1())
    task2 = asyncio.create_task(function2())
    
    # Wait for both tasks to run forever
    await asyncio.gather(task1, task2)

#############
### SETUP ###
#############
i2c, mcpFound, prevBankAPins, currentState, mcp2Found = SP_setup(currentState, config['hardware']['pins']['relais1'], config['hardware']['pins']['relais2'], config['hardware']['pins']['poti1'], config['hardware']['pins']['poti2'], config['hardware']['mcp23017addr'], config['hardware']['pins']['i2c_scl'], config['hardware']['pins']['i2c_sda'], config['hardware']['pins']['mcpIrq'], input_callback, config['inputNames'])
currentState['REED'] = prevBankAPins[3]
currentState['S4'] = prevBankAPins[6]
currentState['S3'] = prevBankAPins[5]
currentState['S2'] = prevBankAPins[4]
currentState['S1'] = prevBankAPins[7]
currentState = SP_writeOutputs(currentState, i2c, currentState['ledB1'], currentState['ledB2'], currentState['ledS1'], currentState['ledS2'], currentState['ledS3'], currentState['outNC1'], currentState['outNC2'], currentState['outNC3'])
print (prevBankAPins)
print('INITIAL VALUES AFTER SETUP')
print(currentState)
print('REED switch is ', currentState['REED'])
print('Main switch S1 is ', currentState['S1'])
print('Switch S2 Zahnrad... is ', currentState['S2'])
print('Switch S3 Feuerd... is ', currentState['S3'])
print('Switch S4 is ', currentState['S4'])

# Initial setup
handle_current_state(currentState)
SP_stopPlayingSound()
time.sleep(0.1)

playSound(11)


####################
### MAIN PROGRAM ###
####################
if mcpFound == False:
    print('EXITING - MCP23017 was not found!')
else:
    # Start the event loop
    asyncio.run(main())

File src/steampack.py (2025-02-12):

from machine import Pin, ADC
import machine
import morutils
from morutils import *

MCP_IODIRA = 0x00  # Controls the direction of the data I/O for port A.
MCP_IODIRB = 0x01  # Controls the direction of the data I/O for port B.
MCP_IPOLA = 0x02  # Configures the polarity on the corresponding GPIO-port bits for port A.
MCP_IPOLB = 0x03  # Configures the polarity on the corresponding GPIO-port bits for port B.
MCP_GPINTENA = 0x04  # Controls the interrupt-on-change for each pin of port A.
MCP_GPINTENB = 0x05  # Controls the interrupt-on-change for each pin of port B.
MCP_DEFVALA = 0x06  # Controls the default comparison value for interrupt-on-change for port A.
MCP_DEFVALB = 0x07  # Controls the default comparison value for interrupt-on-change for port B.
MCP_INTCONA = 0x08  # Controls how the associated pin value is compared for the interrupt-on-change for port A.
MCP_INTCONB = 0x09  # Controls how the associated pin value is compared for the interrupt-on-change for port B.
MCP_IOCON = 0x0A  # Controls the device.
MCP_GPPUA = 0x0C  # Controls the pull-up resistors for the port A pins.
MCP_GPPUB = 0x0D  # Controls the pull-up resistors for the port B pins.
MCP_INTFA = 0x0E  # Reflects the interrupt condition on the port A pins.
MCP_INTFB = 0x0F  # Reflects the interrupt condition on the port B pins.
MCP_INTCAPA = 0x10  # Captures the port A value at the time the interrupt occurred.
MCP_INTCAPB = 0x11  # Captures the port B value at the time the interrupt occurred.
MCP_GPIOA = 0x12  # Reflects the value on the port A.
MCP_GPIOB = 0x13  # Reflects the value on the port B.
MCP_OLATA = 0x14  # Provides access to the port A output latches.
MCP_OLATB = 0x15  # Provides access to the port B output latches.

relais1 = None
relais2 = None
poti1 = None
poti2 = None
globalCallback = None
prevBankAPins = []
mcpIc2Addr = None
mcp2Addr = 0x21
inputNames = []
curValues = []
potiThreshold = 1
poti1PrevValue = 0
poti1Value = 0
poti2PrevValue = 0
poti2Value = 0
poti1Callback = None
poti2Callback = None
i2c = None

def sp_switchRelais(no, status):
    # Low Trigger relais, i.e. False = on
    if no == 1:
        if status == False:
            relais1.value(1)
        else:
            relais1.value(0)
    elif no == 2:
        if status == False:
            relais2.value(1)
        else:
            relais2.value(0)

def SP_setupPins(relais1Pin, relais2Pin, poti1Pin, poti2Pin):
    global relais1, relais2, poti1, poti2
    relais1 = machine.Pin(relais1Pin, machine.Pin.OUT)
    relais2 = machine.Pin(relais2Pin, machine.Pin.OUT)
    poti1 = ADC(Pin(poti1Pin))
    poti2 = ADC(Pin(poti2Pin))
    return relais1, relais2, poti1, poti2

def SP_mcpCallback(pin):
    global prevBankAPins
    changes = []
    curValues = UTIL_convertBinaryValue(i2c.readfrom_mem(mcpIc2Addr, MCP_GPIOA, 1))
    changedOffsets = UTIL_compare_bool_arrays(prevBankAPins, curValues)
    if len(changedOffsets):
        for offset in changedOffsets:
            #print('INPUT ' + inputNames[offset] + ' changed to ' + str(curValues[offset]))
            changes.append([inputNames[offset], curValues[offset]])
        prevBankAPins = curValues
    if len(changes):
        globalCallback(changes)

def SP_mcpSetup(mcpAddr, sclPin, sdaPin, mcpIrqPinNo, irqCallback):
    global i2c, mcpIc2Addr, prevBankAPins
    mcpIc2Addr = mcpAddr

    # Find MCP23017 on i2c
    i2c = machine.I2C(0, scl=machine.Pin(sclPin), sda=machine.Pin(sdaPin), )
    i2cdevices = i2c.scan()
    mcpFound = False
    mcp2Found = False
    for device in i2cdevices:
        if device == mcpIc2Addr:
            print('[x] MCP23017 found on ' + str(hex(mcpIc2Addr)) + ' (' + str(mcpIc2Addr) + ')')
            mcpFound = True
        if device == mcp2Addr:
            print('[x] MCP23017 #2 found on ' + str(hex(mcp2Addr)) + ' (' + str(mcp2Addr) + ')')
            mcp2Found = True
    curValues = []

    if mcpFound == True:
        print('[.] Configuring MCP23017 for program...')
        i2c.writeto_mem(mcpAddr, MCP_IODIRA, b'\xFF')  # Bank A -> all input
        print('[.] Set Bank A to input')
        i2c.writeto_mem(mcpAddr, MCP_GPPUA, b'\xFF')
        print('[.] Set Bank A all pull-up resistors on')
        i2c.writeto_mem(mcpAddr, MCP_GPINTENA, b'\xFF')
        print('[.] Set Bank A IRQ mode')
        i2c.writeto_mem(mcpAddr, MCP_IODIRB, b'\x00')  # Bank B -> all output
        print('[.] Set Bank B to output')
        i2c.writeto_mem(mcpAddr, MCP_GPIOB, b'\x00')
        print('[.] Set Bank B all outputs to 0')
        print('[*] Reading current value of bank A')
        curValues = UTIL_convertBinaryValue(i2c.readfrom_mem(mcpAddr, MCP_GPIOA, 1))
        prevBankAPins = curValues
        mcpIrqPin = machine.Pin(mcpIrqPinNo, machine.Pin.IN)
        mcpIrqPin.irq(trigger=machine.Pin.IRQ_FALLING | machine.Pin.IRQ_RISING, handler=SP_mcpCallback)
        
        print('[.] Configuring MCP23017 #2 for program... (must be set to IO mode 0: 0,0,0')
        i2c.writeto_mem(mcp2Addr, MCP_IODIRA, b'\x00')  # Bank A -> all output
        i2c.writeto_mem(mcp2Addr, MCP_GPIOA, UTIL_bools_to_byte(1, 1, 1, 1, 1, 1, 1, 1)) # all off

    return i2c, mcpFound, curValues, mcp2Found

def SP_setup(currentState, relais1Pin, relais2Pin, poti1Pin, poti2Pin, mcpAddr, sclPin, sdaPin, mcpIrqPinNo, inputCallback, inputNameList):
    global globalCallback, inputNames
    globalCallback = inputCallback
    inputNames = inputNameList
    SP_setupPins(relais1Pin, relais2Pin, poti1Pin, poti2Pin)
    i2c, mcpFound, curValues, mcp2Found = SP_mcpSetup(mcpAddr, sclPin, sdaPin, mcpIrqPinNo, globalCallback)
    currentState['poti1'] = SP_getCurrentPotiValue(1)
    currentState['poti2'] = SP_getCurrentPotiValue(2)
    return i2c, mcpFound, curValues, currentState, mcp2Found

def SP_writeOutputs(currentState, i2c, b1, b2, b3, b4, b5, b6, b7, b8):
    #global currentState
    #print(b1, b2, b3, b4, b5, b6, b7, b8)
    global mcpIc2Addr
    result = UTIL_bools_to_byte(b1, b2, b3, b4, b5, b6, b7, b8)
    #print('[.] Writing outputs to...', result)
    #print(result)
    i2c.writeto_mem(mcpIc2Addr, MCP_GPIOB, result)
    currentState['outNC3'] = b8
    currentState['outNC2'] = b7
    currentState['outNC1'] = b6
    currentState['ledS3'] = b5
    currentState['ledS2'] = b4
    currentState['ledS1'] = b3
    currentState['ledB2'] = b2
    currentState['ledB1'] = b1
    return currentState

def SP_updateOutputs(currentState):
    return SP_writeOutputs(currentState, i2c, currentState['ledB1'], currentState['ledB2'], currentState['ledS1'], currentState['ledS2'], currentState['ledS3'], currentState['outNC1'], currentState['outNC2'], currentState['outNC3'])    

def SP_switchLedS1(currentState, newValue):
    #global currentState
    currentState['ledS1'] = newValue
    return SP_updateOutputs(currentState)

def SP_switchLedS2(currentState, newValue):
    #global currentState
    currentState['ledS2'] = newValue
    return SP_updateOutputs(currentState)
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
